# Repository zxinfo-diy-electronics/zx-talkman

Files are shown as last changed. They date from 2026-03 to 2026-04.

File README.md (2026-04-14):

# zx-talkman
DIY Speech Interface for ZX Spectrum &amp; ZX81 published in Ny Elektronik 1984 issue 10 page 36. Recreated in KiCad as close as possible to original design.

[Short demo](https://youtube.com/shorts/n-YjUCOgAG0?si=_cMUq0j-a8fil3s6) of ZX Spectrum saying 'Hello World' using the interface.

# Original construction
This is the construction as published in the magazine in 1984.

<table>
  <tr>
    <td colspan="3" align="center"></td>
  </tr>
  <tr>
    <td align="center"></td>
    <td align="center"></td>
    <td align="center"> </td>
  </tr>
  <tr>
    <td align="center">Schema</td>
    <td align="center">PCB</td>
    <td align="center">Components layout</td>
  </tr>
</table>

# Setting up KiCad 9
For this project you also need ZXInfo symbol and footprints from [here](https://github.com/zxinfo-diy-electronics/ZXINFO_LIBRARY). Follow the intructions to add the libraries to your KiCad setup.

# Recreated construction
The main goal was to get the schema redrawn in KiCad and a first try at a PCB, in order to build a version to check if everything works.

## Programming the ZX-TALKMAN
The interface is controled by outputting to port 31 (dec). On ZX Spectrum this can be done using the BASIC command out. On ZX81 you will need to write a short M/C program to send data to the interface. (May come later).

## Hello world on ZX Spectrum
```BASIC
10 READ data
20 IF data > 63 THEN OUT 31,0: STOP
30 OUT 31, data
40 GO TO 10
1000 DATA 27,51,45,53,46,52,45,21,0, 64
```

## Compatible commercial speech interfaces
OUTPUT to any port with A4 low will activate the SP0256. This means that this interface is "compatible" with the following interfaces:
- Cheetah Sweet Talker
- Fuller Orator

Some more details below.

# Planned for v1.1
Replace the CLOCK part with a crystal as described in the SP0256-AL2 documentation.


- Disbale the amplifier when the SP0256 is inactive, to reduce output noise.
- Make output SBY & LRQ line readable from computer for better control and compability with other interfaces.
- Jumper to enable/disable control of WAIT line

# version 1.0

## KNOWN issues with v1.0
It seems like the 'reset' SP0256 does not always work as intented when the computer is powered up first time. Just turn it off and on again and it should be reset correctly.

From Magazine over KiCad to PCB.

| Schema | KiCad | PCB |
| --- | ----- | --- |
|KiCad Schema|KiCad PCB|PCB

## produced version of v1.0
| Building | Final | In use |
| --- | ----- | --- |
|||

## BOM v1.0
You will need the following components:

| Reference | Qty | Value |
|---|-----|---|
| C1 | 1 | 820pF, ceramic |
| C2 | 1 | 220pF, ceramic |
| C3,C4,C9,C10,C15 | 5 | 100nF, MKT |
| C5,C7 | 2 | 4,7uF, tantalum |
| C6 | 1 | 470pF, ceramic |
| C8 | 1 | 10uF, electrolytic |
| C11,C12 | 2 | 100uF, electrolytic |
| C13,C14 | 2 | 100nF, ceramic |
| HT1 | 1 | Speaker0.5W/8R |
| IC3 | 1 | SP0256-AL2 (watch out for fakes)|
| J1 | 1 | ZX_Spectrum_Connector_48K |
| Q1 | 1 | BC548 |
| R1 | 1 | 4.7K |
| R2,R10 | 2 | 100R |
| R3 | 1 | 330R |
| R4 | 1 | 100K |
| R5 | 1 | 33K |
| R6 | 1 | 1M |
| R7 | 1 | 4,7K |
| R8 | 1 | 10K, logarithmic |
| R9 | 1 | 10R |
| U1 | 1 | 74LS00 |
| U2 | 1 | 74LS32 |
| U3 | 1 | LM386 |

# Other interfaces using SP0256 - and what I know about them :-)

## Currah uSpeech
Probaly the most popular speech interface for ZX Spectrum is the [Currah uSpeech](https://spectrumcomputing.co.uk/entry/8067/ZX-Spectrum/Currah_MicroSpeech), wich had suport in multiple [games](https://spectrumcomputing.co.uk/entry/1000081/Hardware/Currah_MicroSpeech). It comes with it's own overlay ROM and hardware to control it - making it easy to use from BASIC. Looks like it can be controlled by your own code, but that I need to investigate.

## Cheetah Sweet Talker
The [Sweet Talker](https://spectrumcomputing.co.uk/entry/1000063/Hardware/Cheetah_Sweet_Talker) is a simple interface, almost like this DIY - in fact the demo program [Chatbox](https://spectrumcomputing.co.uk/entry/10467/ZX-Spectrum/Chatbox) - can be used with this interface right out of the box (mainly because of simple address decoding). You can see it demonstraded in this [video](https://youtube.com/shorts/8_oEiTdBw0U)
- Output data to port 7
- NEEDS SBY to WAIT connection

## dk'tronics speech synthesiser
Another speech interface is the dk'tronics [speech synthesiser](https://spectrumcomputing.co.uk/entry/1000128/Hardware/DKTronics_Speech_Synthesiser). According to the manual, it's controlled by:
- Output data to port 127
- Read status from port 127 (data = 127 = READY)
Comes with a program to make it easy to use from BASIC, need to investigate it further - to see if it will work with this interface.

## Fuller Orator
Fuller [Orator](https://spectrumcomputing.co.uk/entry/1000165/Hardware/Fuller_Orator) - yes, it runs the [demonstration](https://youtube.com/shorts/HEt_V7jbKws?si=R-SY6JT0dKBFEpfD) program as well.
- Output data to port 159
- Works best if SBY to WAIT is removed

### Games supporting Fuller Orator
- [Jungle Fever](https://spectrumcomputing.co.uk/entry/2660/ZX-Spectrum/Jungle_Fever)
- [Chuckie Egg](https://spectrumcomputing.co.uk/entry/958/ZX-Spectrum/Chuckie_Egg)
- [Ziggurat](https://spectrumcomputing.co.uk/entry/5855/ZX-Spectrum/Ziggurat)
- [Key Speaker](https://spectrumcomputing.co.uk/entry/13384/ZX-Spectrum/Key_Speaker) (A bit like Currah Speech, talks while you type)
- [Spectrum Voice Chess](https://spectrumcomputing.co.uk/entry/5599/ZX-Spectrum/Spectrum_Voice_Chess) (Orator version, speaks to fast - needs to wait for chip ready?)
- [Dimension Destructor](https://spectrumcomputing.co.uk/entry/1394/ZX-Spectrum/Dimension_Destructors) (NOT confirmed to work)

## Datel Vox Box

## William Stuart Chatterbox I & II

# Tools and useful links
- SP0256-AL2 [Datasheet](https://www.bitsavers.org/components/gi/speech/General_Instrument_-_SP0256A-AL2_datasheet_(Radio_Shack_276-1784)_-_Apr1984.pdf)
- Be aware [Genuine vs Counterfeit.](https://www.smbaker.com/counterfeitfakejustplainbad-sp0256a-al2-chips)
- Online [text to speech](https://greg-kennedy.com/sp0256-tts/)

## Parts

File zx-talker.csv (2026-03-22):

Reference | Qty | Value | DNP | Exclude from BOM | Exclude from Board | Footprint | Datasheet
C1 | 1 | 820pF (cer) |  |  |  | Capacitor_THT:C_Disc_D4.3mm_W1.9mm_P5.00mm | ~
C2 | 1 | 220pF (cer) |  |  |  | Capacitor_THT:C_Disc_D4.3mm_W1.9mm_P5.00mm | ~
C3,C4,C9,C10,C15 | 5 | 100nF, MKT |  |  |  | Capacitor_THT:C_Rect_L7.0mm_W2.5mm_P5.00mm | ~
C5,C7 | 2 | 4,7uF, tantal |  |  |  | Capacitor_THT:CP_Radial_Tantal_D4.5mm_P5.00mm | ~
C6 | 1 | 470pF (cer) |  |  |  | Capacitor_THT:C_Disc_D4.3mm_W1.9mm_P5.00mm | ~
C8 | 1 | 10uF, lyt |  |  |  | Capacitor_THT:CP_Radial_D5.0mm_P2.50mm | ~
C11,C12 | 2 | 100uF, lyt |  |  |  | Capacitor_THT:CP_Radial_D5.0mm_P2.50mm | ~
C13,C14 | 2 | 100nF |  |  |  | Capacitor_THT:C_Disc_D3.0mm_W1.6mm_P2.50mm | ~
HT1 | 1 | HT |  |  |  | Connector_PinHeader_2.54mm:PinHeader_1x02_P2.54mm_Horizontal | ~
IC3 | 1 | SP0256-AL2 |  |  |  | Package_DIP:DIP-28_W15.24mm_Socket
J1 | 1 | ZX_Spectrum_Connector_48K |  |  |  | ZXINFO_FOOTPRINT:EDGE_ZX_SPECTRUM
Q1 | 1 | BC548 |  |  |  | Package_TO_SOT_THT:TO-92_Inline | https://www.onsemi.com/pub/Collateral/BC550-D.pdf
R1 | 1 | 4.7K |  |  |  | Potentiometer_THT:Potentiometer_Piher_PT-10-V10_Vertical | ~
R2,R10 | 2 | 100 |  |  |  | Resistor_THT:R_Axial_DIN0207_L6.3mm_D2.5mm_P10.16mm_Horizontal | ~
R3 | 1 | 330 |  |  |  | Resistor_THT:R_Axial_DIN0207_L6.3mm_D2.5mm_P10.16mm_Horizontal | ~
R4 | 1 | 100K |  |  |  | Resistor_THT:R_Axial_DIN0207_L6.3mm_D2.5mm_P10.16mm_Horizontal | ~
R5 | 1 | 33K |  |  |  | Resistor_THT:R_Axial_DIN0207_L6.3mm_D2.5mm_P10.16mm_Horizontal | ~
R6 | 1 | 1M |  |  |  | Resistor_THT:R_Axial_DIN0207_L6.3mm_D2.5mm_P10.16mm_Horizontal | ~
R7 | 1 | 4,7K |  |  |  | Resistor_THT:R_Axial_DIN0207_L6.3mm_D2.5mm_P10.16mm_Horizontal | ~
R8 | 1 | 10K, log |  |  |  | Connector_PinHeader_2.54mm:PinHeader_1x03_P2.54mm_Horizontal | ~
R9 | 1 | 10 |  |  |  | Resistor_THT:R_Axial_DIN0207_L6.3mm_D2.5mm_P10.16mm_Horizontal | ~
U1 | 1 | 74LS00 |  |  |  | Package_DIP:DIP-14_W7.62mm | http://www.ti.com/lit/gpn/sn74ls00
U2 | 1 | 74LS32 |  |  |  | Package_DIP:DIP-14_W7.62mm | http://www.ti.com/lit/gpn/sn74LS32
U3 | 1 | LM386 |  |  |  | Package_DIP:DIP-8_W7.62mm | http://www.ti.com/lit/ds/symlink/lm386.pdf

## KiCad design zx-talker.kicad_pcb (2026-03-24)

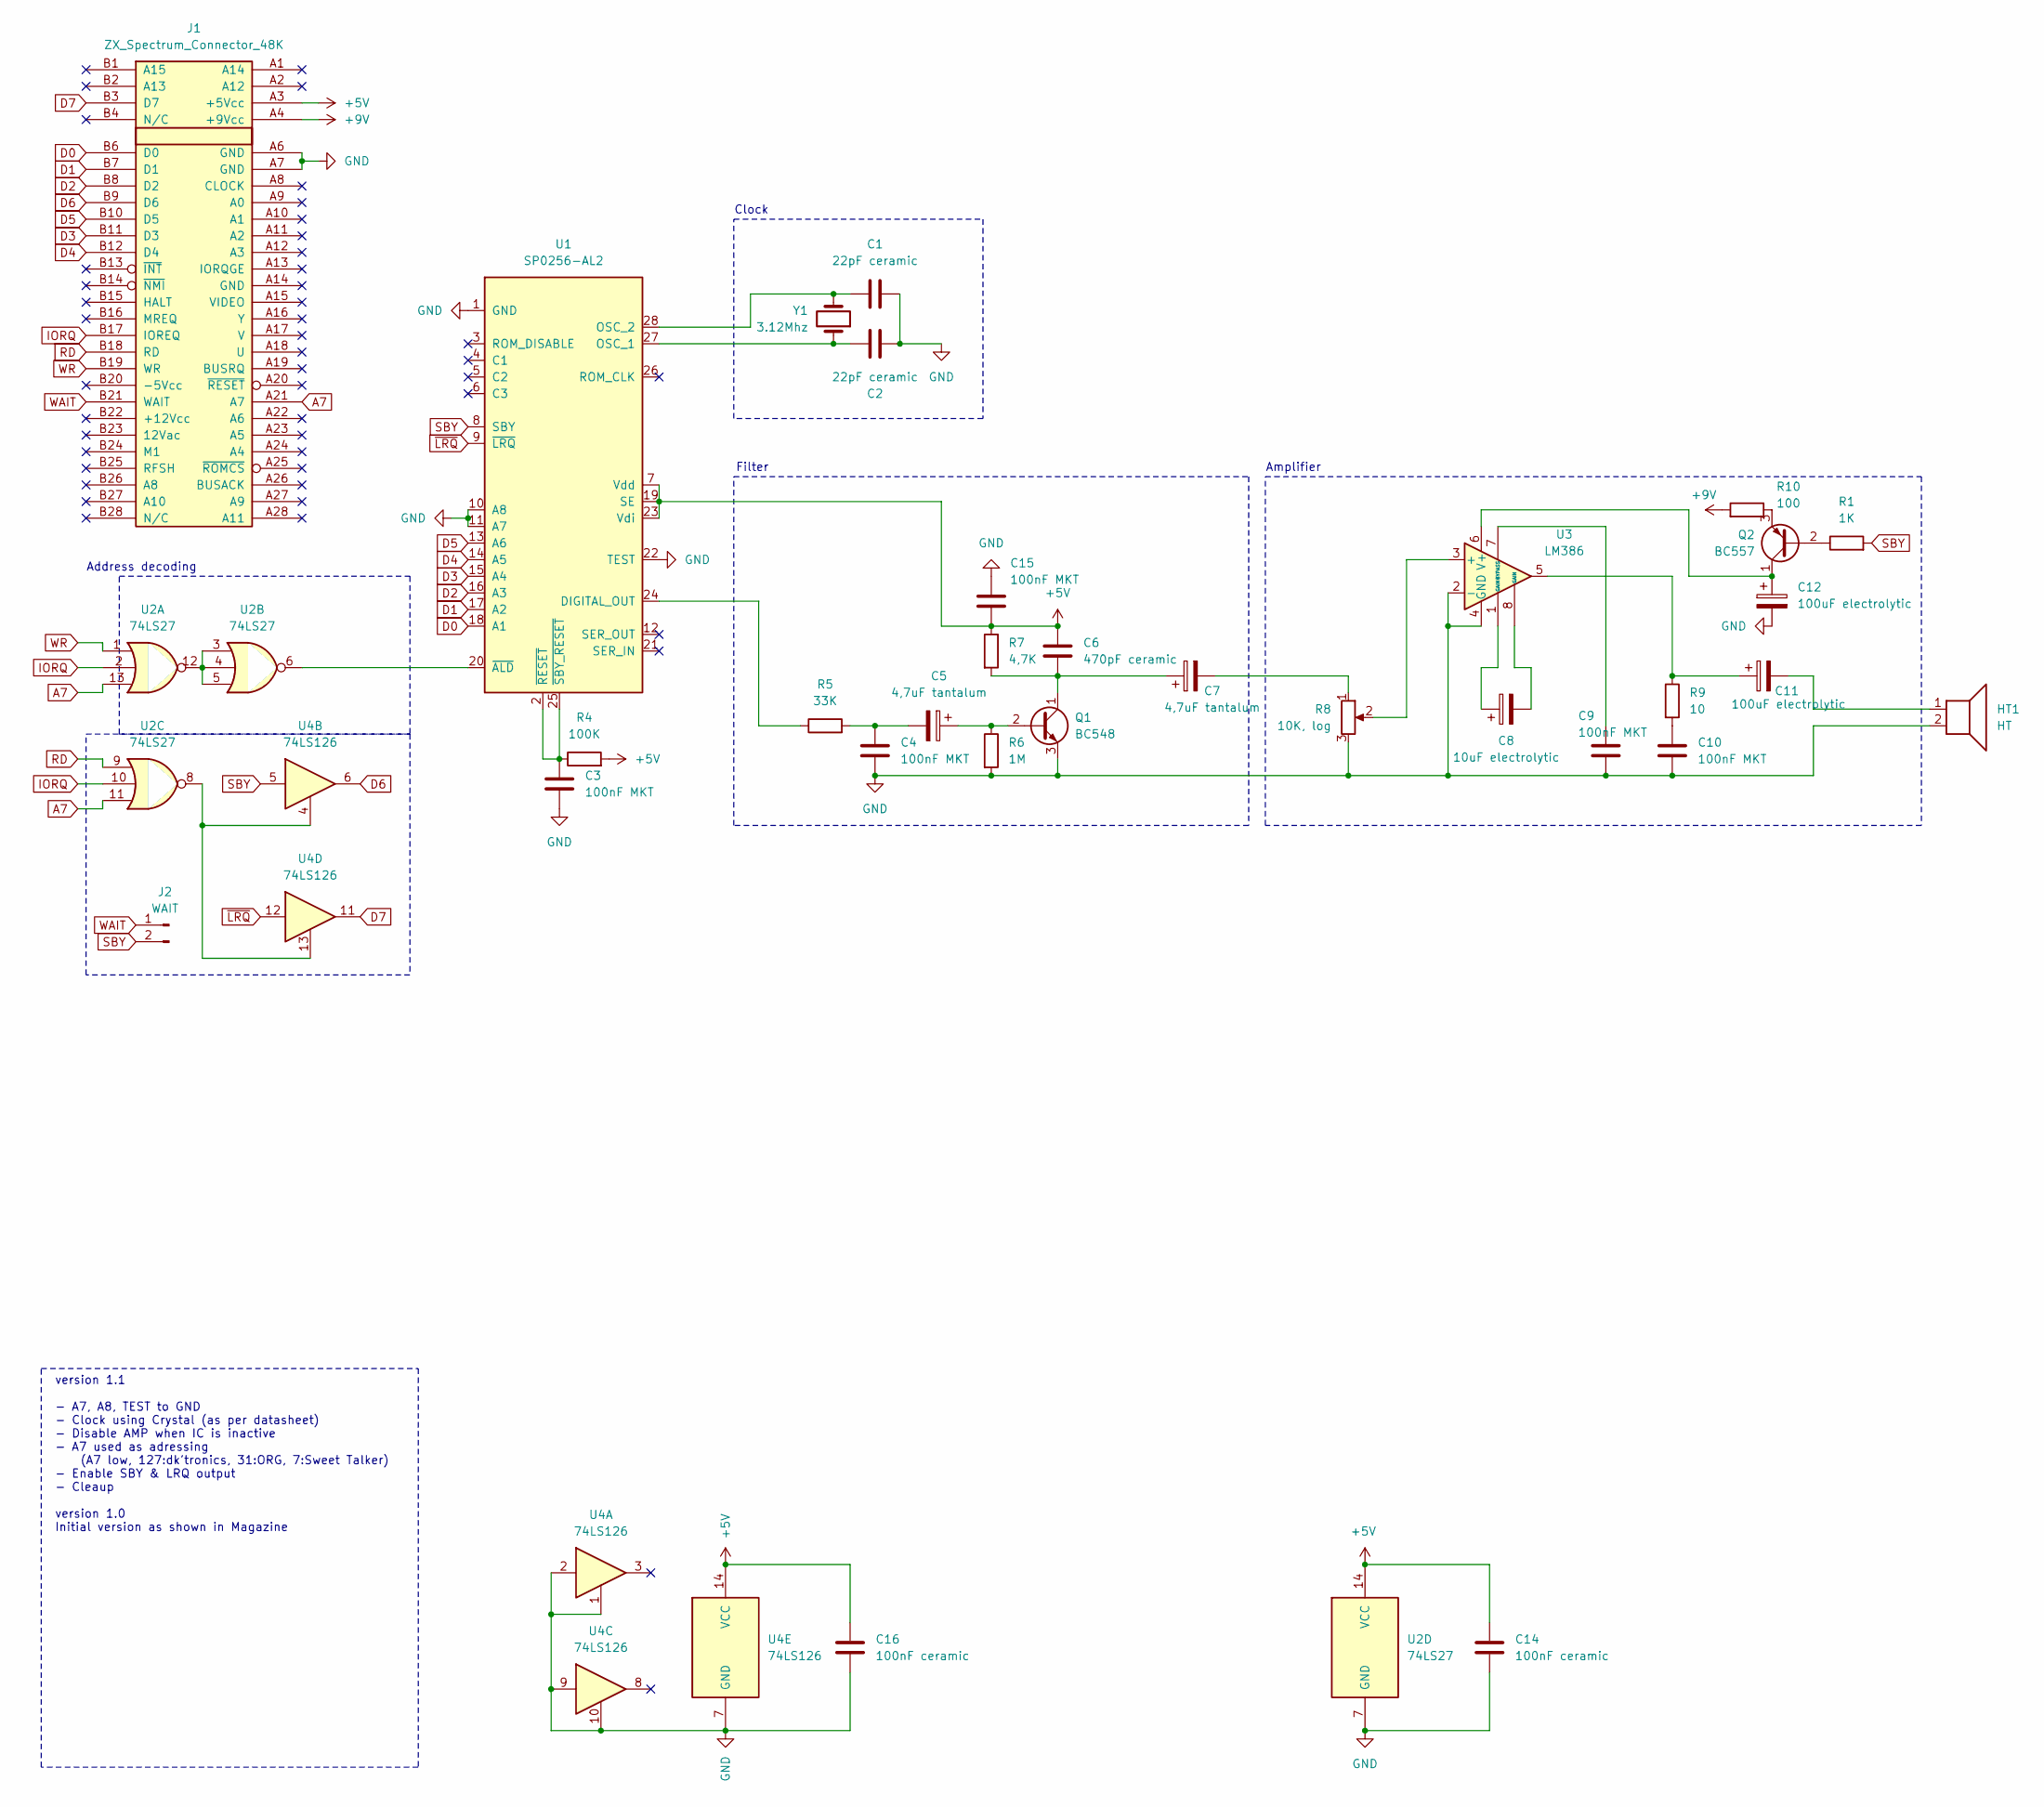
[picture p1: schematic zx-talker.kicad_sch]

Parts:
C1, C2: 22pF ceramic; C_Rect_L7.0mm_W2.5mm_P5.00mm
C3, C4, C9, C10, C15: 100nF MKT; C_Rect_L7.0mm_W2.5mm_P5.00mm
C5, C7: 4,7uF tantalum; CP_Radial_Tantal_D4.5mm_P5.00mm
C6: 470pF ceramic; C_Disc_D4.3mm_W1.9mm_P5.00mm
C8: 10uF electrolytic; CP_Radial_D5.0mm_P2.50mm
C11, C12: 100uF electrolytic; CP_Radial_D5.0mm_P2.50mm
C14, C16: 100nF ceramic; C_Disc_D3.0mm_W1.6mm_P2.50mm
HT1: HT; PinHeader_1x02_P2.54mm_Horizontal
J1: ZX_Spectrum_Connector_48K; EDGE_ZX_SPECTRUM
J2: WAIT; PinHeader_1x02_P2.54mm_Horizontal
Q1: BC548; TO-92_Inline
Q2: BC557; TO-92_Inline
R1: 1K; R_Axial_DIN0207_L6.3mm_D2.5mm_P10.16mm_Horizontal
R4: 100K; R_Axial_DIN0207_L6.3mm_D2.5mm_P10.16mm_Horizontal
R5: 33K; R_Axial_DIN0207_L6.3mm_D2.5mm_P10.16mm_Horizontal
R6: 1M; R_Axial_DIN0207_L6.3mm_D2.5mm_P10.16mm_Horizontal
R7: 4,7K; R_Axial_DIN0207_L6.3mm_D2.5mm_P10.16mm_Horizontal
R8: 10K, log; PinHeader_1x03_P2.54mm_Horizontal
R9: 10; R_Axial_DIN0207_L6.3mm_D2.5mm_P10.16mm_Horizontal
R10: 100; R_Axial_DIN0207_L6.3mm_D2.5mm_P10.16mm_Horizontal
U1: SP0256-AL2; DIP-28_W15.24mm_Socket
U2: 74LS27; DIP-14_W7.62mm
U3: LM386; DIP-8_W7.62mm
U4: 74LS126; DIP-14_W7.62mm
Y1: 3.12Mhz; Crystal_HC49-U_Vertical

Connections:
+5V: C6.1, C14.1, C15.2, C16.1, J1.A3 (+5Vcc), R4.2, R7.1, U1.7 (Vdd), U1.19 (SE), U1.23 (Vdi), U2.14 (VCC), U4.14 (VCC)
+9V: J1.A4 (+9Vcc), R10.2
A7: J1.A21 (A7), U2.11, U2.13
D0: J1.B6 (D0), U1.18 (A1)
D1: J1.B7 (D1), U1.17 (A2)
D2: J1.B8 (D2), U1.16 (A3)
D3: J1.B11 (D3), U1.15 (A4)
D4: J1.B12 (D4), U1.14 (A5)
D5: J1.B10 (D5), U1.13 (A6)
D6: J1.B9 (D6), U4.6
D7: J1.B3 (D7), U4.11
GND: C1.2, C2.1, C3.2, C4.2, C9.2, C10.2, C12.2, C14.2, C15.1, C16.2, HT1.2, J1.A6 (GND), J1.A7 (GND), Q1.3 (E), R6.2, R8.3, U1.1 (GND), U1.10 (A8), U1.11 (A7), U1.22 (TEST), U2.7 (GND), U3.2 (-), U3.4 (GND), U4.1, U4.2, U4.7 (GND), U4.9, U4.10
IORQ: J1.B17 (IOREQ), U2.2, U2.10
unnamed: C4.1, C5.2, R5.2
unnamed: C7.2, R8.1
unnamed: C8.1, U3.1 (GAIN)
unnamed: C8.2, U3.8 (GAIN)
unnamed: C10.1, R9.2
unnamed: C11.1, R9.1, U3.5
unnamed: C11.2, HT1.1
unnamed: C5.1, Q1.2 (B), R6.1
unnamed: C6.2, C7.1, Q1.1 (C), R7.2
unnamed: Q2.2 (B), R1.1
unnamed: C12.1, Q2.1 (C), U3.6 (V+)
unnamed: Q2.3 (E), R10.1
unnamed: R5.1, U1.24 (DIGITAL_OUT)
unnamed: C2.2, U1.27 (OSC_1), Y1.1
unnamed: C1.1, U1.28 (OSC_2), Y1.2
unnamed: U1.20 (~ALD), U2.6
unnamed: C3.1, R4.1, U1.2 (~RESET), U1.25 (~SBY_RESET)
unnamed: U2.8, U4.4, U4.13
unnamed: U2.3, U2.4, U2.5, U2.12
unnamed: R8.2, U3.3 (+)
unnamed: C9.1, U3.7 (BYPASS)
RD: J1.B18 (RD), U2.9
SBY: J2.2, R1.2, U1.8 (SBY), U4.5
WAIT: J1.B21 (WAIT), J2.1
WR: J1.B19 (WR), U2.1
~LRQ: U1.9 (~LRQ), U4.12

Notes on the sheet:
Amplifier
version 1.1 - A7, A8, TEST to GND - Clock using Crystal (as per datasheet) - Disable AMP when IC is inactive - A7 used as adressing (A7 low, 127:dk'tronics, 31:ORG, 7:Sweet Talker) - Enable SBY & LRQ output - Cleaup version 1.0 Initial version as shown in Magazine
Clock
Address decoding
Filter

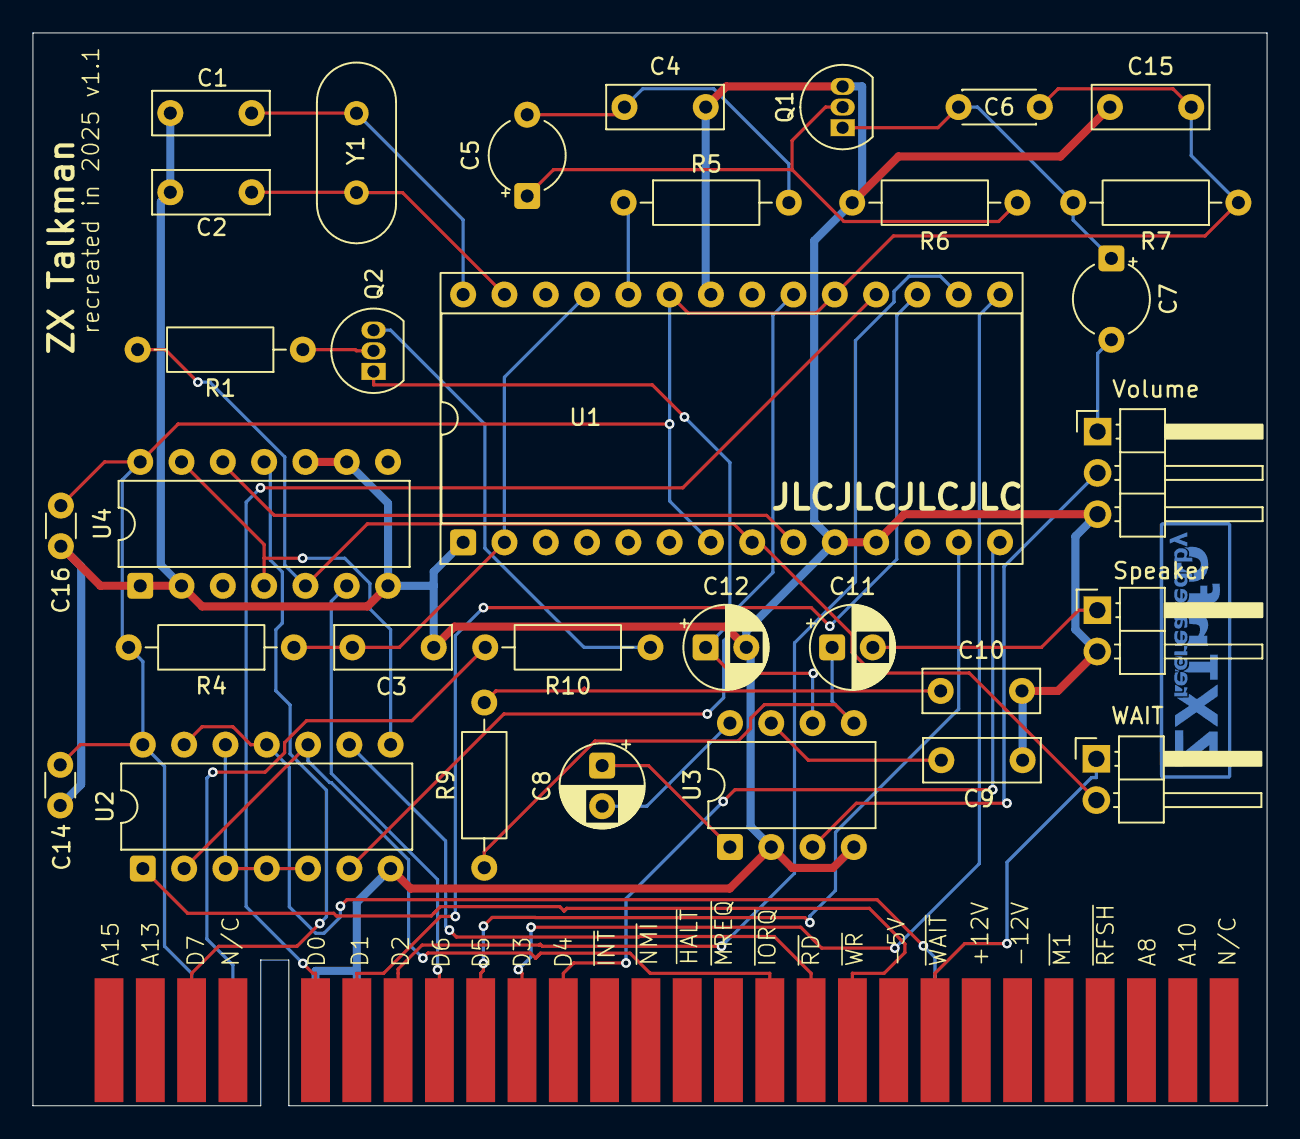
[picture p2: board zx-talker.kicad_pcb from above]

Board: 2 copper layers, 75.9 x 66.0 mm, 34 parts (1 on the bottom side), 39 nets.

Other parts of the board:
G200: LOGO; ZXInfo_kicad_logo_copper_16.5x5

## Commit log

2026-03-22 Add BOM v1.0 section to README
    Added BOM v1.0 section with required components.
2026-03-22 Initial version
    [zx-talker-B_Cu.gbr, zx-talker-B_Mask.gbr, zx-talker-B_Paste.gbr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]
2026-03-22 Update README with KiCad setup instructions
    Added instructions for setting up KiCad 9 and required libraries.
2026-03-22 Update README.md for KiCad setup and versioning
2026-03-24 updated with improvements
    [zx-talker.kicad_pcb, zx-talker.kicad_sch]
